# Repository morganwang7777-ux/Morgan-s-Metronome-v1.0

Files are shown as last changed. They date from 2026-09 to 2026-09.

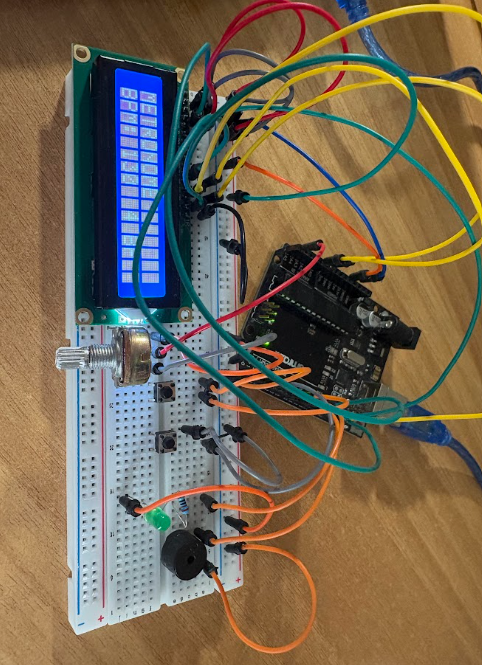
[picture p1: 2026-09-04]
images/breadboard-prototype.png

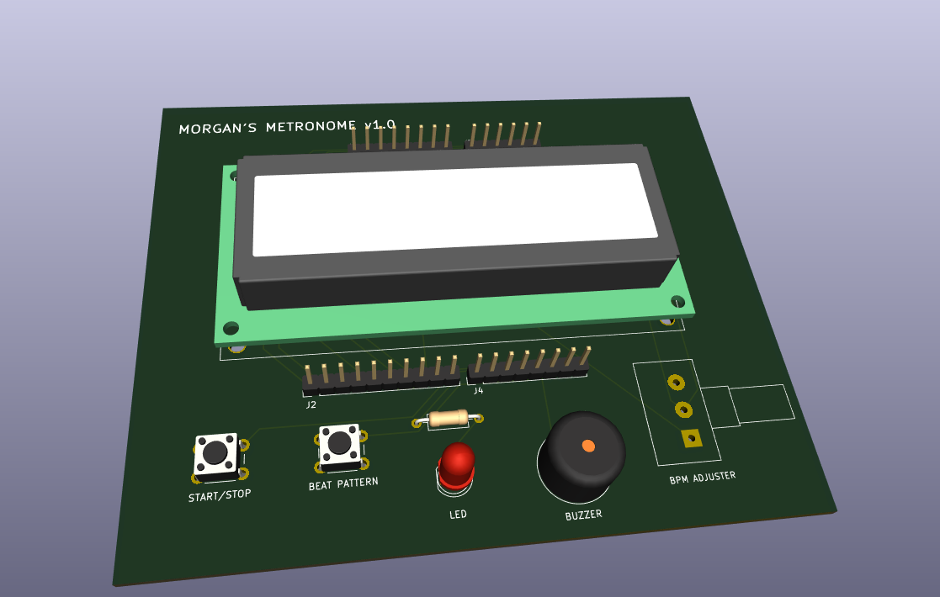
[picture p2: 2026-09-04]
images/3d-top.png

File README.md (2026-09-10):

# Morgan's Metronome v1.0

Arduino-based digital metronome developed from a breadboard prototype into a custom KiCad PCB shield. (First Project)
I built this project to learn how to use Arduino hardware and software and to create a working metronome instead of having to purchase one to practice my sax.

## Features

- 100 mm × 90 mm size shield
- Adjustable 40–180 BPM
- 5 BPM increments using a 10k potentiometer
- Start/Stop button
- 2–7 beat pattern selection
- Accented first beat
- 16x2 LCD display
- LED beat indicator
- Passive buzzer
- Custom 2-layer Arduino Uno shield PCB

## Development

The project started as a simple buzzer and LED metronome.

I originally used `delay()` for timing, but testing against a reference metronome showed that the BPM was inaccurate. I replaced this with `millis()`-based timing so the beat interval could be tracked more reliably.

I also replaced button-based BPM control with a potentiometer. Since the analog input was too sensitive, I rounded the BPM to 5 BPM increments.

After finishing the breadboard prototype
- I recreated the circuit in KiCad
- Ran ERC/DRC checks
- Selected and measured component footprints
- Routed the PCB, added a bottom GND plane
- Generated Gerber files 

## Hardware

- Arduino Uno
- 16x2 LCD
- 10k potentiometer
- Passive buzzer
- 5mm LED
- 220Ω resistor
- 2 pushbuttons

## Future Improvements
Tap tempo
More rhythm modes
Standalone PCB without the Arduino Uno
Enclosure
Improved buzzer volume control

## Repository

```text
firmware/   Arduino code
hardware/   KiCad schematic and PCB
gerbers/    Manufacturing files
images/     Project screenshots

Version

Morgan's Metronome v1.0

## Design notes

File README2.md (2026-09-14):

# Mechanical Enclosure

The mechanical enclosure for this project was designed by **Jordan Lin https://github.com/jordanlin0603/Jordan-s-Metronome-Casing-**.

Jordan created a custom **SolidWorks enclosure** around the metronome PCB and supporting plate hardware. The enclosure was designed to securely package the electronics while maintaining access to the PCB and allowing the board to be removed when required.

## Enclosure Features

- Custom tapered SolidWorks casing
- **100 mm × 90 mm** PCB mounting cavity
- Separate **71 mm × 55 mm** secondary plate cavity
- Wiring clearance and pass-through features
- **M3 screw** pivot system
- Two movable PCB retaining rails
- Mechanical rail stops
- SolidWorks assembly testing to verify rail movement and PCB accessibility

## Design Revision

The original retention design used a single rail across the PCB.

During assembly testing, this rail was found to obstruct access to the PCB controls. The design was therefore revised to use separate **top and bottom retaining rails**.

This allows the PCB to remain securely mounted while keeping its controls accessible and making the board easier to remove when required.

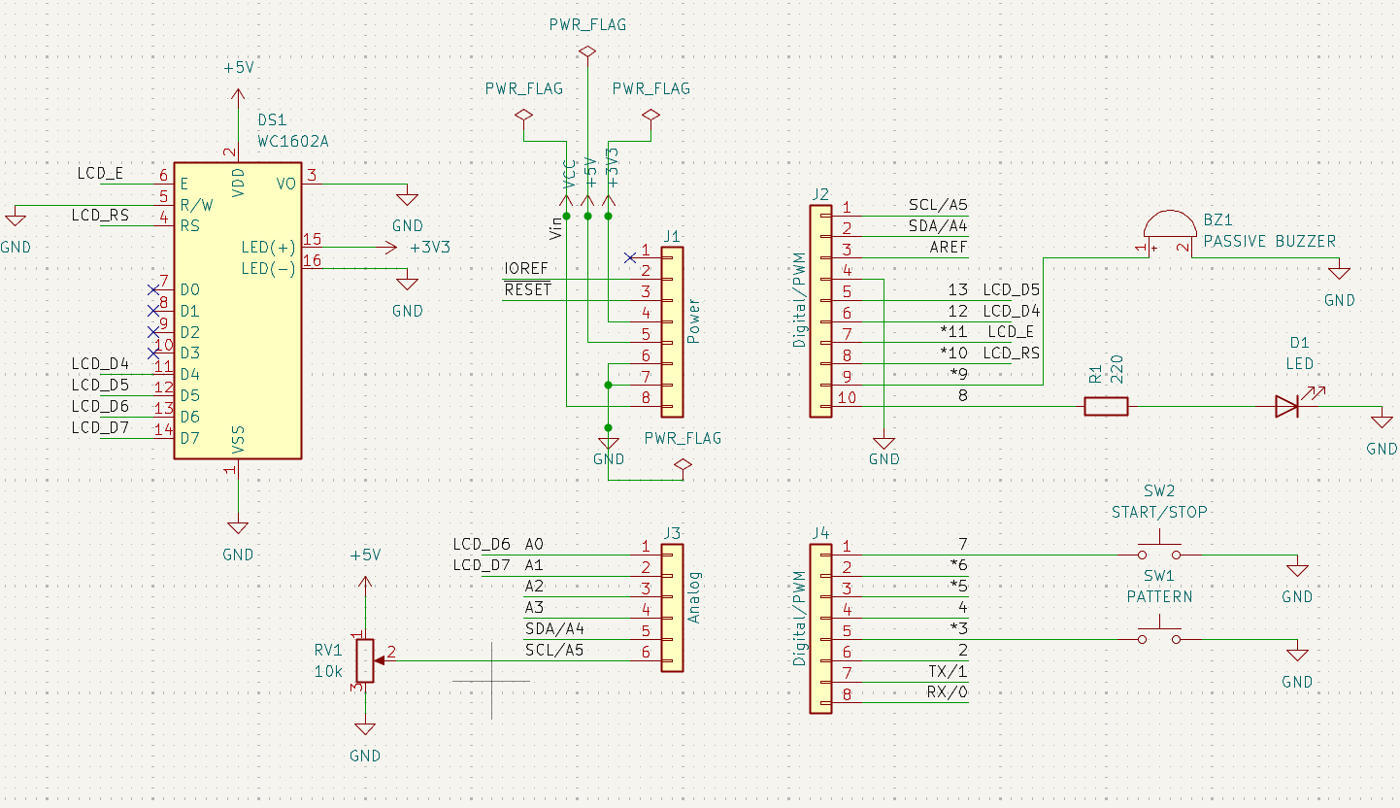
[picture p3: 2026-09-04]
images/schematic.png

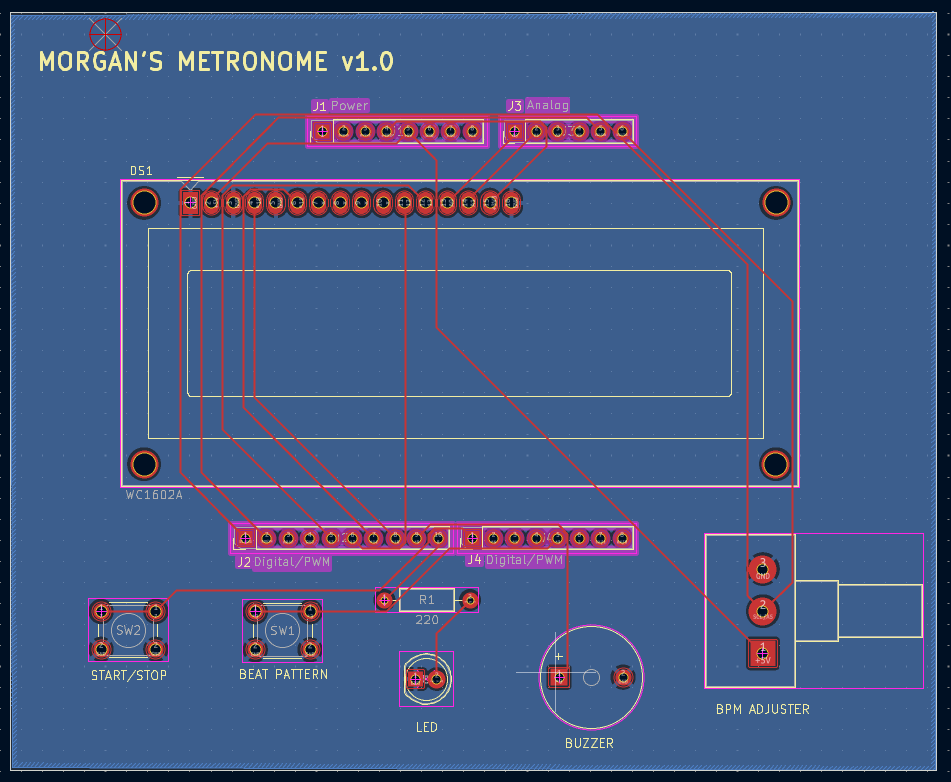
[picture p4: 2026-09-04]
images/pcb-layout.png

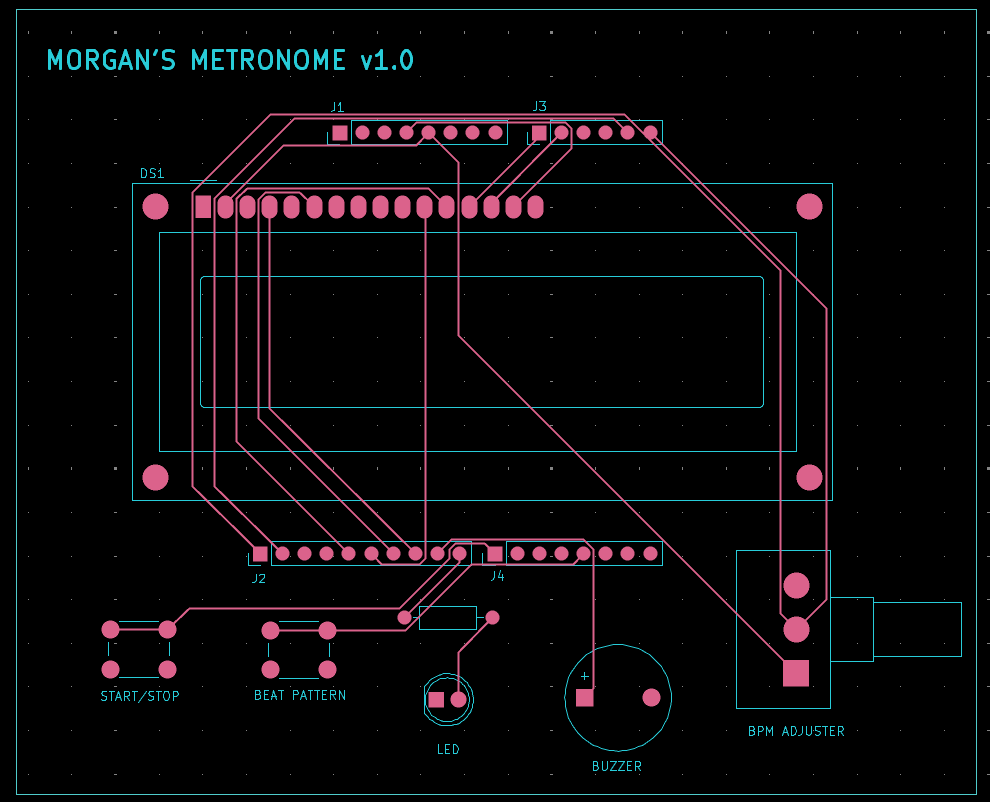
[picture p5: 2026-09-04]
images/gerber-front.png

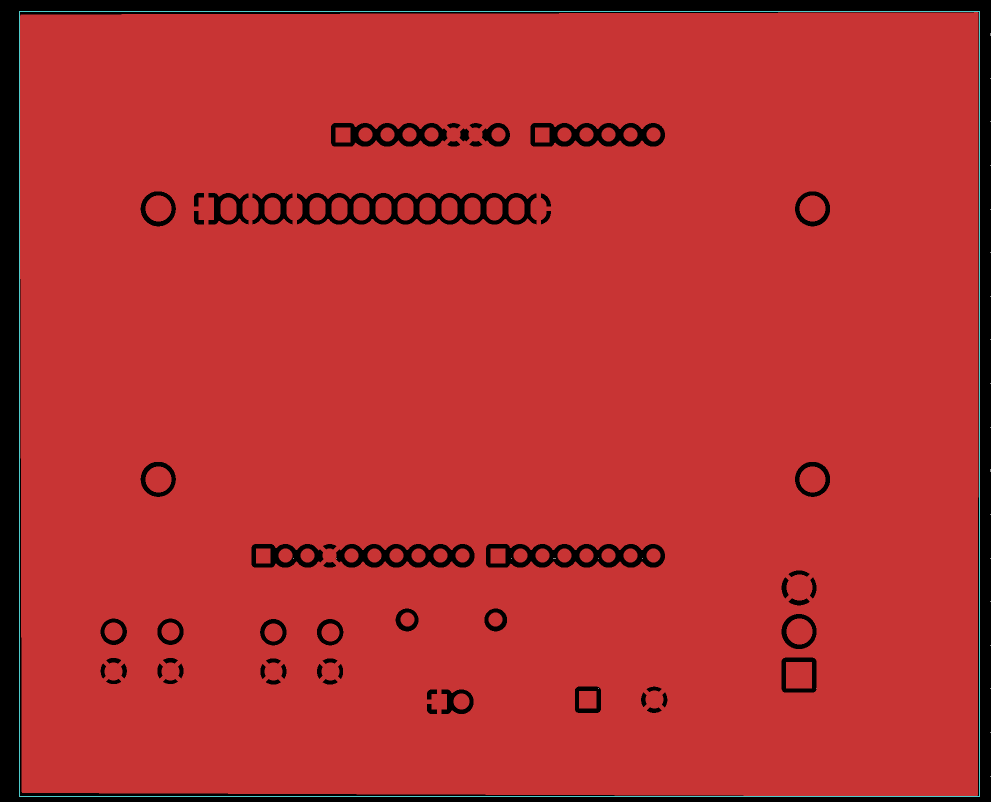
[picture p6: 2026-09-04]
images/gerber-back.png

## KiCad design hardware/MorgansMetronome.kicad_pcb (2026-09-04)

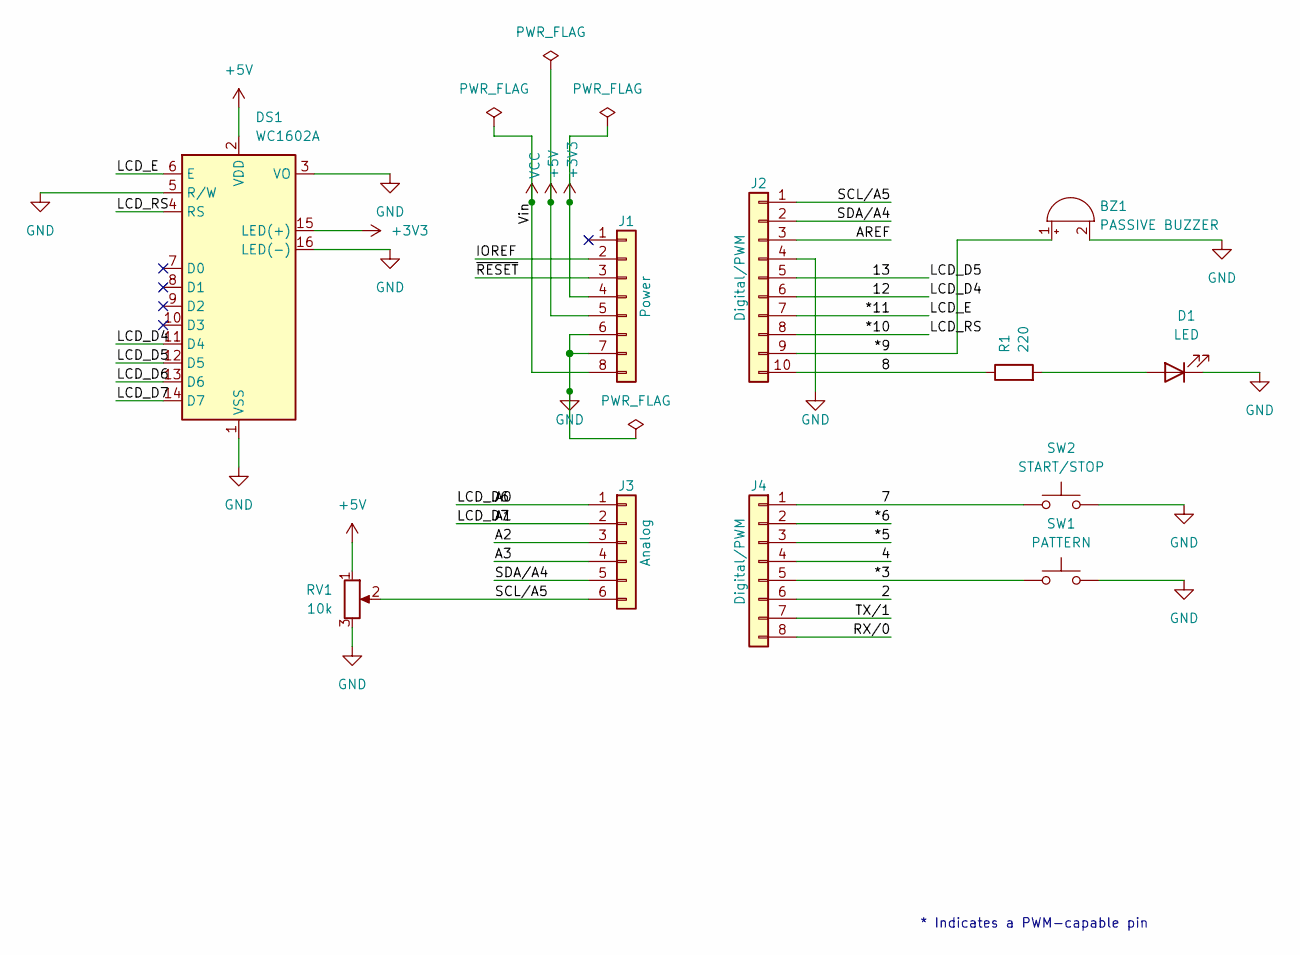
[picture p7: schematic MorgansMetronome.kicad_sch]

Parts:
BZ1: PASSIVE BUZZER; Buzzer_12x9.5RM7.6
D1: LED; LED_D5.0mm
DS1: WC1602A
J1: Power; PinHeader_1x08_P2.54mm_Vertical
J2: Digital/PWM; PinHeader_1x10_P2.54mm_Vertical
J3: Analog; PinHeader_1x06_P2.54mm_Vertical
J4: Digital/PWM; PinHeader_1x08_P2.54mm_Vertical
R1: 220; R_Axial_DIN0207_L6.3mm_D2.5mm_P10.16mm_Horizontal
RV1: 10k; Potentiometer_Alps_RK163_Single_Horizontal
SW1: PATTERN; SW_PUSH_6mm_H4.3mm
SW2: START/STOP; SW_PUSH_6mm_H4.3mm

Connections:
+3V3: DS1.15 (LED(+)), J1.4
+5V: DS1.2 (VDD), J1.5, RV1.1
/2: J4.6
/4: J4.4
/7: J4.1, SW2.1
/8: J2.10, R1.1
/12: DS1.11 (D4), J2.6
/13: DS1.12 (D5), J2.5
/*3: J4.5, SW1.1
/*5: J4.3
/*6: J4.2
/*9: BZ1.1 (+), J2.9
/*10: DS1.4 (RS), J2.8
/*11: DS1.6 (E), J2.7
/A0: DS1.13 (D6), J3.1
/A1: DS1.14 (D7), J3.2
/A2: J3.3
/A3: J3.4
/AREF: J2.3
/IOREF: J1.2
/RX/0: J4.8
/SCL/A5: J2.1, J3.6, RV1.2
/SDA/A4: J2.2, J3.5
/TX/1: J4.7
/~RESET: J1.3
GND: BZ1.2 (-), D1.1 (K), DS1.1 (VSS), DS1.3 (VO), DS1.5 (R/W), DS1.16 (LED(-)), J1.6, J1.7, J2.4, RV1.3, SW1.2, SW2.2
unnamed: D1.2 (A), R1.2
VCC: J1.8

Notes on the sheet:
* Indicates a PWM-capable pin

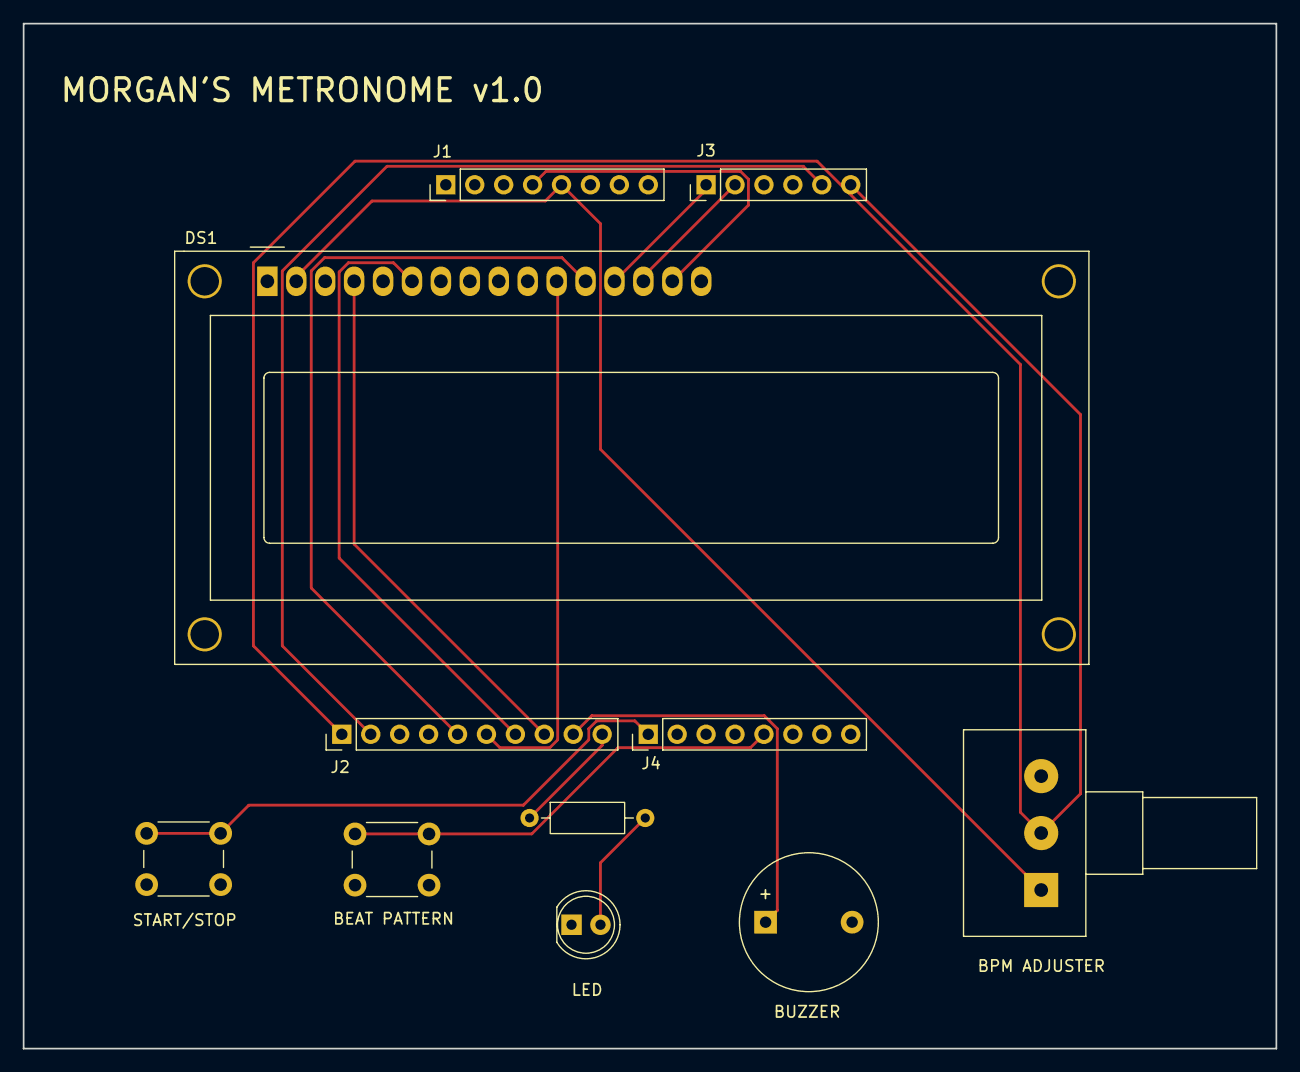
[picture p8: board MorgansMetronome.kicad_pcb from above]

Board: 2 copper layers, 110.0 x 90.0 mm, 11 parts (0 on the bottom side), 16 nets.

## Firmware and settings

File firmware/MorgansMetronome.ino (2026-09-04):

#include <LiquidCrystal.h>

LiquidCrystal lcd(10, 11, 12, 13, A0, A1);

bool running = false;

int bpm = 40;
int patternOptions[] = {4, 5, 6, 7, 2, 3};
int patternIndex = 0;
int patternLength = 4;

int currentBeat = 0;

unsigned long lastBeat = 0;
unsigned long beatInterval = 0;

void setup() {
  pinMode(8, OUTPUT);
  pinMode(9, OUTPUT);
  pinMode(7, INPUT_PULLUP);
  pinMode(3, INPUT_PULLUP);

  Serial.begin(9600);

  lcd.begin(16, 2);
  lcd.clear();

  lcd.setCursor(0, 0);
  lcd.print("METRONOME");

  lcd.setCursor(0, 1);
  lcd.print("BPM: 40  4 BP");

  beatInterval = 60000UL / bpm;

  Serial.println("Ready!");
}

void loop() {
  int potValue = analogRead(A5);

  int newBpm = map(potValue, 0, 1023, 40, 180);

  newBpm = ((newBpm + 2) / 5) * 5;

  if (newBpm != bpm) {
    bpm = newBpm;

    beatInterval = 60000UL / bpm;

    lcd.setCursor(0, 1);
    lcd.print("BPM: ");
    lcd.print(bpm);
    lcd.print("  ");
    lcd.print(patternLength);
    lcd.print(" BP ");

    Serial.print("BPM: ");
    Serial.println(bpm);
  }

  if (digitalRead(3) == LOW) {
    patternIndex++;

    if (patternIndex >= 6) {
      patternIndex = 0;
    }

    patternLength = patternOptions[patternIndex];

    currentBeat = 0;

    lcd.setCursor(0, 1);
    lcd.print("BPM: ");
    lcd.print(bpm);
    lcd.print("  ");
    lcd.print(patternLength);
    lcd.print(" BP ");

    Serial.print("Pattern: ");
    Serial.print(patternLength);
    Serial.println(" beats");

    while (digitalRead(3) == LOW) {
      delay(10);
    }
  }

  if (digitalRead(7) == LOW) {
    running = !running;

    if (running) {
      Serial.println("STARTED");

      lcd.setCursor(0, 0);
      lcd.print("RUNNING         ");

      currentBeat = 0;

      lastBeat = millis();

      digitalWrite(8, HIGH);

      tone(9, 400);
    }
    else {
      Serial.println("STOPPED");

      lcd.setCursor(0, 0);
      lcd.print("METRONOME       ");

      digitalWrite(8, LOW);
      noTone(9);
    }

    while (digitalRead(7) == LOW) {
      delay(10);
    }
  }

  if (running) {
    unsigned long currentTime = millis();

    if (currentTime - lastBeat >= beatInterval) {
      lastBeat += beatInterval;

      currentBeat++;

      if (currentBeat >= patternLength) {
        currentBeat = 0;
      }

      digitalWrite(8, HIGH);

      if (currentBeat == 0) {
        tone(9, 400);
      }
      else {
        tone(9, 200);
      }

      delay(60);

      digitalWrite(8, LOW);
      noTone(9);
    }
  }
}

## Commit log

2026-09-04 Add PCB manufacturing files
    [MorgansMetronome-B_Cu.gbr, MorgansMetronome-B_Mask.gbr, MorgansMetronome-B_Silkscreen.gbr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]
2026-09-04 Add KiCad schematic and PCB design
